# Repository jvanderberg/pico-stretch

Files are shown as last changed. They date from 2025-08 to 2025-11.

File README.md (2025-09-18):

# Pico Stretch

This is an RP2350B Dev board that breaks out all 48 GPIO pins.

It follows the original footprint of the RP2040 dev board, but adds 12 pins on each side.

Pinout:

```
1	GPIO0	        64	VBUS
2	GPIO1	        63	VSYS
3	GND	            62	GND
4	GPIO2	        61	3v3
5	GPIO3	        60	3v3_EN
6	GPIO4	        59	ADC_VREF
7	GPIO5	        58	GPIO28
8	GND	            57	GND
9	GPIO6	        56	GPIO27
10	GPIO7	        55	GPIO26
11	GPIO8	        54	RUN
12	GPIO9	        53	GPIO22
13	GND 	        52	GND
14	GPIO10	        51	GPIO21
15	GPIO11	        50	GPIO20
16	GPIO12	        49	GPIO19
17	GPIO13	        48	GPIO18
18	GND	            47	GND
19	GPIO14	        46	GPIO17
20	GPIO15	        45	GPIO16
21	GPIO23	        44	GPIO47/ADC7
22	GPIO24          43	GPIO46/ADC6
23	GPIO25	        42	GPIO45/ADC5
24	GPIO29	        41	GPIO44/ADC4
25	GPIO30	        40	GPIO43/ADC3
26	GPIO31	        39	GPIO42/ADC2
27	GPIO32	        38	GPIO41/ADC1
28	GPIO33	        37	GPIO40/ADC0
29	GPIO34	        36	GPIO39
30	GPIO35	        35	GPIO38
31  GND             34  GND
32  GPIO36          33  GPIO37
```

## Production files for JLCPCB

The production files for JLCPCB are in the 'production' directory.

pico-stretch.zip is the zipped Gerber files.

bom.csv and positions.csv are the Bill of materials and placements files respectively.

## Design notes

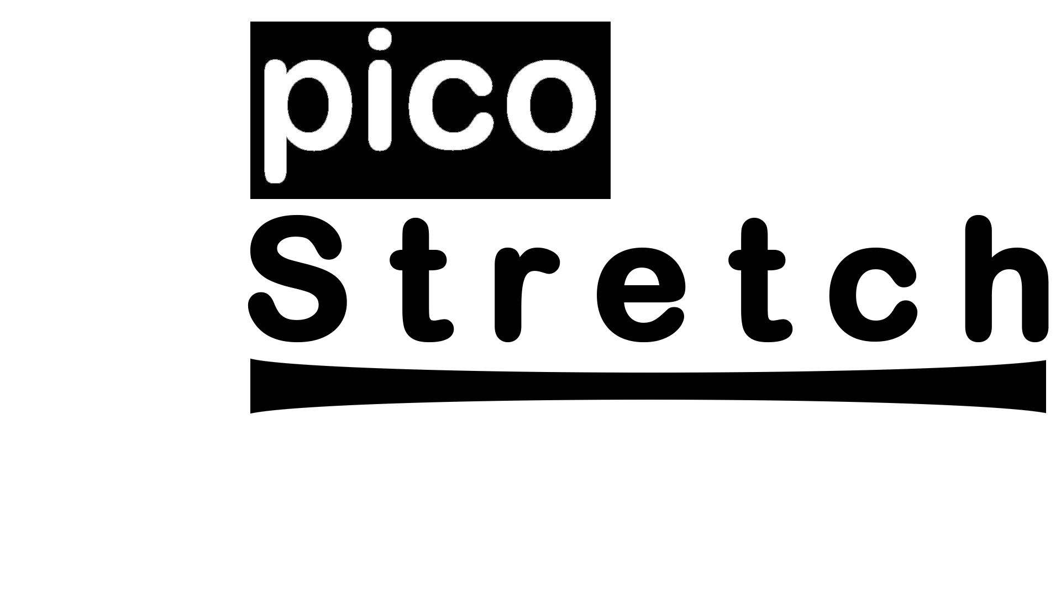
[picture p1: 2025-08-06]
picostretch.png

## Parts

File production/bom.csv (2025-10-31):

Designator | Footprint | Quantity | Value | LCSC Part #
BOOT1, RESET1 | KEY-SMD_4P-L4.2-W3.2-P2.20-LS5.1-TL | 2 | K2-1808SN-A4SW-01 | C92589
C1, C13, C16, C2, C21, C22, C23, C36, C7, C8 | C_0402 | 10 | 100nF | C1525
C10, C12 | C_0603 | 2 | 4.7uF | C19666
C11, C19 | C_0402 | 2 | 4.7uF | C23733
C15, C38, C39, C9 | C_0603 | 4 | 100nF | C14663
C17, C18 | C_0402 | 2 | 15pF | C1548
C24 | C_0603 | 1 | 4.7nF | C53987
C3, C4, C5, C6 | C_0402 | 4 | 100nF
C37, C40 | C_0603 | 2 | 10uF | C19702
D1 | POWERDI-123_L2.8-W1.8-LS3.7-RD | 1 | ~ | C110493
D2, D3 | D0402-BI | 2 | RCLAMP0521P.TCT-MS | C3029033
J2 | PinHeader_1x03_P2.54mm_Vertical | 1 | Conn_01x03_Pin
J4 | Castellated_Pad_64 | 1 | Conn_01x64_Castellated_Pads
L1 | IND-SMD_L2.0-W1.6_AOTA-B201610S3R3-101-T | 1 | ~ | C42411119
PWR_LED1 | D_0603 | 1 | Red | C2286
R1, R4 | R_0402 | 2 | 5.1kΩ | C25905
R10, R14, R16, R9 | R_0402 | 4 | 10kΩ | C25744
R11 | R_0402 | 1 | 100kΩ | C25741
R12 | R_0402 | 1 | 2kΩ | C4109
R15 | R_0402 | 1 | 470Ω | C25117
R2, R3, R6 | R_0402 | 3 | 33Ω | C25105
R28 | R_0603 | 1 | 1kΩ | C21190
R5 | R_0402 | 1 | 1kΩ | C11702
R7 | R_0603 | 1 | 1Ω | C22936
R8 | R_0603 | 1 | 200Ω | C8218
TP1, TP2 | TestPoint_Pad_1.0x1.0mm | 2 | TestPoint
U1 | QFN-80_L10.0-W10.0-P0.40-TL-EP3.4 | 1 | ~ | C42415655
U3 | SOT-23-5_L3.0-W1.7-P0.95-LS2.8-BR | 1 | ~ | C427602
U4 | SOIC-8_L5.3-W5.3-P1.27-LS8.0-BL | 1 | Winbond W25Q128JVSIQ | C97521
U5 | rpi_rmc20452t | 1 | RPI Radio Module 2
U6 | SOIC-8_3.9x4.9mm_P1.27mm | 1 | ESP-PSRAM32
USB1 | USB-C-SMD_TYPE-C-6PIN-2MD-073 | 1 | ~ | C2765186
X1 | CRYSTAL-SMD_4P-L3.2-W2.5-BL | 1 | ~ | C20625731

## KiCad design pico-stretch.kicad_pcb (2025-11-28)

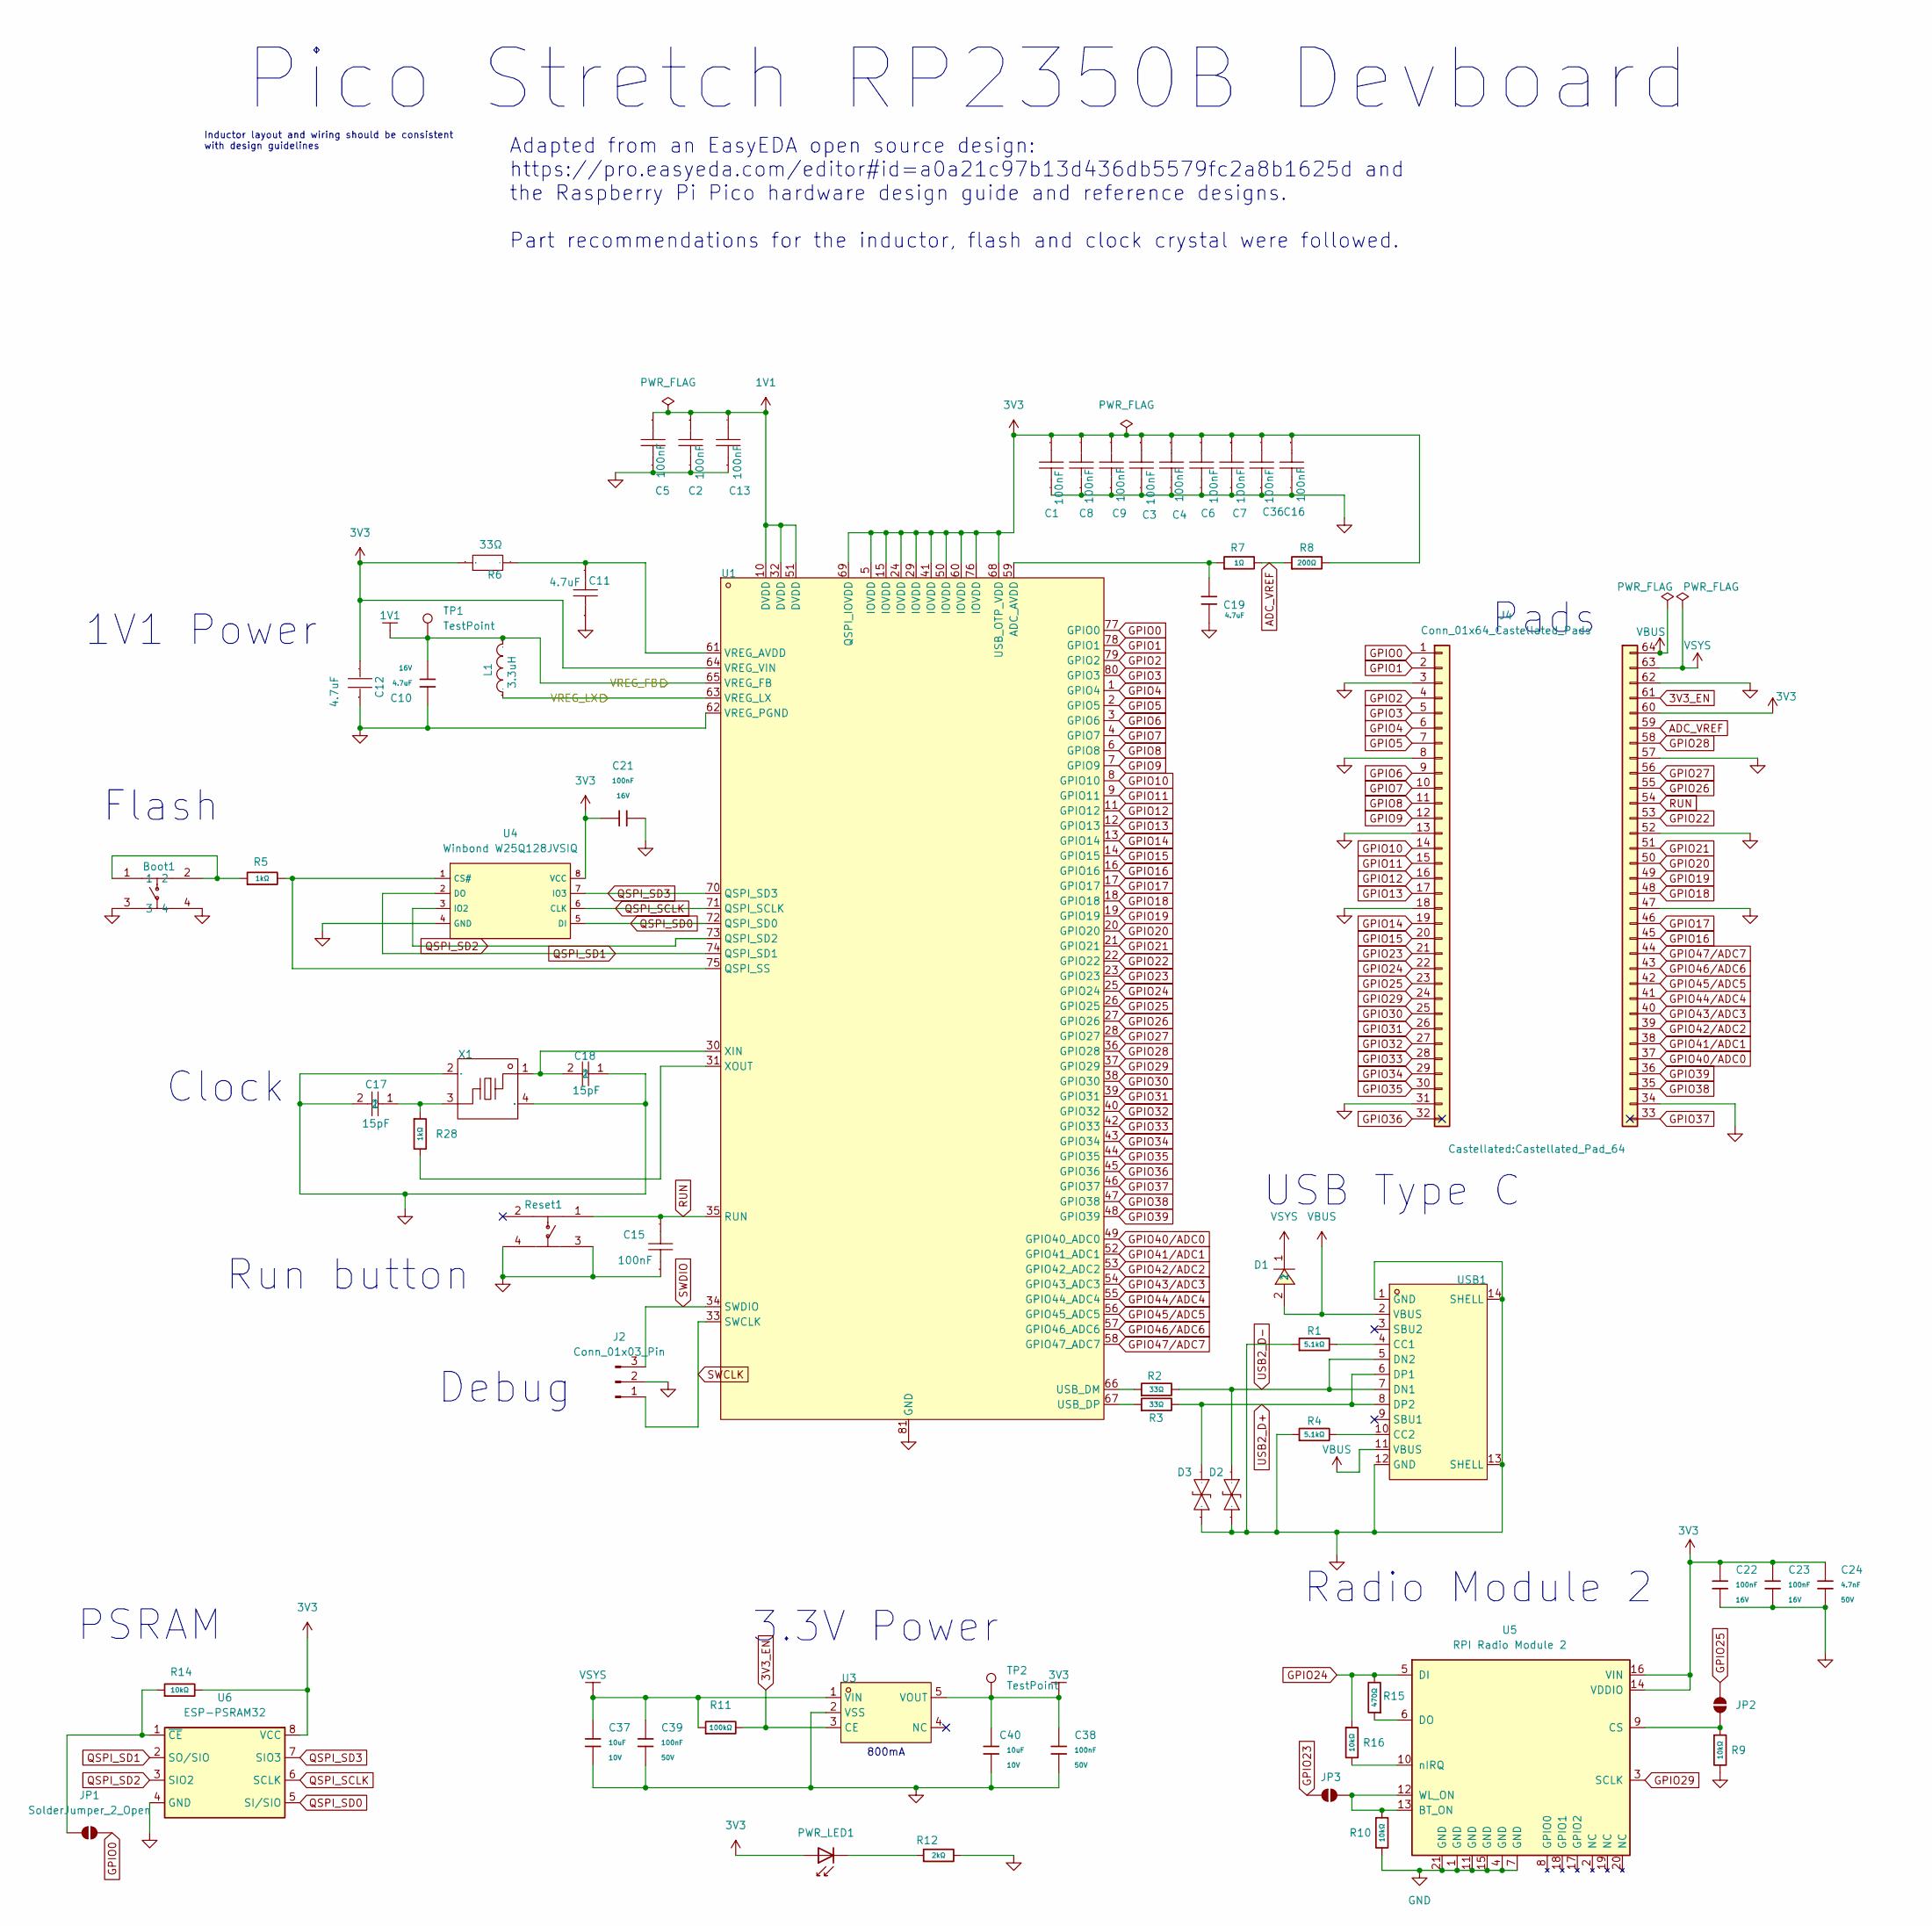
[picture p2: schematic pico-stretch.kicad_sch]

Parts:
Boot1: K2-1808SN-A4SW-01; KEY-SMD_4P-L4.2-W3.2-P2.20-LS5.1-TL; Manufacturer Part K2-1808SN-A4SW-01; LCSC Part Name 4.2mm*3.25mm
C1, C2, C3, C4, C5, C6, C7, C8, C13, C16, C36: 100nF; C0402; Manufacturer Part CL05B104KO5NNNC; LCSC Part Name 100nF ±10% 16V
C9, C15: 100nF; C0402; Voltage Rating 50V; Manufacturer Part CC0603KRX7R9BB104; LCSC Part Name 100nF ±10% 50V
C10: 4.7uF; C_0603; Voltage Rated 16V; Tolerance ±10%; Part CL10A475KO8NNNC; LCSC C19666
C11: 4.7uF; Manufacturer Part CL05A475MP5NRNC; LCSC Part Name 4.7uF ±20% 10V
C12: 4.7uF; Manufacturer Part CL10A475KO8NNNC; LCSC Part Name 4.7uF ±10% 16V
C17, C18: 15pF; C0402; Manufacturer Part 0402CG150J500NT; LCSC Part Name 15pF ±5% 50V
C19: 4.7uF; C_0402; Voltage Rated 10V; Tolerance ±20%; Part CL05A475MP5NRNC; LCSC C23733
C21, C22, C23: 100nF; C_0402; Voltage Rated 16V; Tolerance ±10%; Part CL05B104KO5NNNC; LCSC C1525
C24: 4.7nF; C_0603; Voltage Rated 50V; Tolerance ±10%; Part 0603B472K500NT; LCSC C53987
C37, C40: 10uF; C_0603; Voltage Rated 10V; Tolerance ±10%; Part CL10A106KP8NNNC; LCSC C19702
C38, C39: 100nF; C_0603; Voltage Rated 50V; Tolerance ±10%; Part CC0603KRX7R9BB104; LCSC C14663
D1: POWERDI-123_L2.8-W1.8-LS3.7-RD; Manufacturer Part DFLS130L-7; LCSC Part Name 电压:30V 电流:1A
D2, D3: RCLAMP0521P.TCT-MS; D0402-BI; Manufacturer Part RCLAMP0521P.TCT-MS; LCSC Part Name 双向TVS 5V截止 4A峰值脉冲 丝印N
J2: Conn_01x03_Pin; PinHeader_1x03_P2.54mm_Vertical
J4: Conn_01x64_Castellated_Pads; Castellated_Pad_64
JP1, JP2, JP3: SolderJumper_2_Open; SolderJumper-2_P1.3mm_Open_Pad1.0x1.5mm
L1: IND-SMD_L2.0-W1.6_AOTA-B201610S3R3-101-T; Manufacturer Part AOTA-B201610S3R3-101-T; LCSC Part Name AOTA-B201610S3R3-101-T
PWR_LED1: Red; D_0603; Part KT-0603R; LCSC C2286
R1, R4: 5.1kΩ; R_0402; Overload Voltage (Max) 50V; Tolerance ±1%; Part 0402WGF5101TCE; LCSC C25905
R2, R3: 33Ω; R_0402; Overload Voltage (Max) 50V; Tolerance ±1%; Part 0402WGF330JTCE; LCSC C25105
R5: 1kΩ; R_0402; Overload Voltage (Max) 50V; Tolerance ±1%; Part 0402WGF1001TCE; LCSC C11702
R6: 33Ω; R0402; Manufacturer Part 0402WGF330JTCE; LCSC Part Name 33Ω ±1% 62.5mW 厚膜电阻
R7: 1Ω; R_0603; Overload Voltage (Max) 75V; Tolerance ±1%; Part 0603WAF100KT5E; LCSC C22936
R8: 200Ω; R_0603; Overload Voltage (Max) 75V; Tolerance ±1%; Part 0603WAF2000T5E; LCSC C8218
R9, R10, R14, R16: 10kΩ; R_0402; Overload Voltage (Max) 50V; Tolerance ±1%; Part 0402WGF1002TCE; LCSC C25744
R11: 100kΩ; R_0402; Overload Voltage (Max) 50V; Tolerance ±1%; Part 0402WGF1003TCE; LCSC C25741
R12: 2kΩ; R_0402; Overload Voltage (Max) 50V; Tolerance ±1%; Part 0402WGF2001TCE; LCSC C4109
R15: 470Ω; R_0402; Overload Voltage (Max) 50V; Tolerance ±1%; Part 0402WGF4700TCE; LCSC C25117
R28: 1kΩ; R_0603; Overload Voltage (Max) 75V; Tolerance ±1%; Part 0603WAF1001T5E; LCSC C21190
Reset1: K2-1808SN-A4SW-01; KEY-SMD_4P-L4.2-W3.2-P2.20-LS5.1-TL; Manufacturer Part K2-1808SN-A4SW-01; LCSC Part Name 4.2mm*3.25mm
TP1, TP2: TestPoint; TestPoint_Pad_1.0x1.0mm
U1: QFN-80_L10.0-W10.0-P0.40-TL-EP3.4; Manufacturer Part RP2350B; LCSC Part Name RP2350B
U3: SOT-23-5_L3.0-W1.7-P0.95-LS2.8-BR; Manufacturer Part ME6217C33M5G; LCSC Part Name ME6217C33M5G
U4: Winbond W25Q128JVSIQ; SOIC-8_L5.3-W5.3-P1.27-LS8.0-BL; Part W25Q128JVSIQ; LCSC C97521
U5: RPI Radio Module 2; rpi_rmc20452t
U6: ESP-PSRAM32; SOIC-8_3.9x4.9mm_P1.27mm
USB1: USB-C-SMD_TYPE-C-6PIN-2MD-073; Manufacturer Part TYPE-C 16PIN 2MD(073); LCSC Part Name Type-C 母 卧贴
X1: Manufacturer Part ABM8-272-T3; LCSC Part Name ABM8-272-T3

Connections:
1V1: C2.1, C5.1, C10.2, C13.2, L1.2, TP1.1, U1.10 (DVDD), U1.32 (DVDD), U1.51 (DVDD), U1.65 (VREG_FB)
3V3: C1.1, C3.1, C4.1, C6.1, C7.1, C8.2, C9.2, C12.2, C16.1, C21.1, C22.1, C23.1, C24.1, C36.2, C38.1, C40.1, J4.60, PWR_LED1.2, R6.1, R8.2, R14.2, TP2.1, U1.5 (IOVDD), U1.15 (IOVDD), U1.24 (IOVDD), U1.29 (IOVDD), U1.41 (IOVDD), U1.50 (IOVDD), U1.60 (IOVDD), U1.64 (VREG_VIN), U1.68 (USB_OTP_VDD), U1.69 (QSPI_IOVDD), U1.76 (IOVDD), U3.5 (VOUT), U4.8 (VCC), U5.14 (VDDIO), U5.16 (VIN), U6.8 (VCC)
3V3_EN: J4.61, R11.2, U3.3 (CE)
/VREG_LX: L1.1, U1.63 (VREG_LX)
ADC_VREF: J4.59, R7.2, R8.1
GND: Boot1.3, Boot1.4, C1.2, C2.2, C3.2, C4.2, C5.2, C6.2, C7.2, C8.1, C9.1, C10.1, C11.1, C12.1, C13.1, C15.1, C16.2, C17.2, C18.1, C19.2, C21.2, C22.2, C23.2, C24.2, C36.1, C37.2, C38.2, C39.2, C40.2, D2.1, D3.1, J2.2, J4.3, J4.8, J4.13, J4.18, J4.31, J4.34, J4.47, J4.52, J4.57, J4.62, R1.1, R4.1, R9.2, R10.2, R12.2, Reset1.3, Reset1.4, U1.62 (VREG_PGND), U1.81 (GND), U3.2 (VSS), U4.4 (GND), U5.1 (GND), U5.4 (GND), U5.7 (GND), U5.11 (GND), U5.15 (GND), U5.21 (GND), U6.4 (GND), USB1.1 (GND), USB1.12 (GND), USB1.13 (SHELL), USB1.14 (SHELL), X1.2 (GND), X1.4 (GND)
GPIO0: J4.1, JP1.2 (B), U1.77 (GPIO0)
GPIO1: J4.2, U1.78 (GPIO1)
GPIO2: J4.4, U1.79 (GPIO2)
GPIO3: J4.5, U1.80 (GPIO3)
GPIO4: J4.6, U1.1 (GPIO4)
GPIO5: J4.7, U1.2 (GPIO5)
GPIO6: J4.9, U1.3 (GPIO6)
GPIO7: J4.10, U1.4 (GPIO7)
GPIO8: J4.11, U1.6 (GPIO8)
GPIO9: J4.12, U1.7 (GPIO9)
GPIO10: J4.14, U1.8 (GPIO10)
GPIO11: J4.15, U1.9 (GPIO11)
GPIO12: J4.16, U1.11 (GPIO12)
GPIO13: J4.17, U1.12 (GPIO13)
GPIO14: J4.19, U1.13 (GPIO14)
GPIO15: J4.20, U1.14 (GPIO15)
GPIO16: J4.45, U1.16 (GPIO16)
GPIO17: J4.46, U1.17 (GPIO17)
GPIO18: J4.48, U1.18 (GPIO18)
GPIO19: J4.49, U1.19 (GPIO19)
GPIO20: J4.50, U1.20 (GPIO20)
GPIO21: J4.51 (Pin_61), U1.21 (GPIO21)
GPIO22: J4.53, U1.22 (GPIO22)
GPIO23: J4.21, JP3.1 (A), U1.23 (GPIO23)
GPIO24: J4.22, R15.2, R16.1, U1.25 (GPIO24), U5.5 (DI)
GPIO25: J4.23, JP2.2 (B), U1.26 (GPIO25)
GPIO26: J4.55, U1.27 (GPIO26)
GPIO27: J4.56, U1.28 (GPIO27)
GPIO28: J4.58, U1.36 (GPIO28)
GPIO29: J4.24, U1.37 (GPIO29), U5.3 (SCLK)
GPIO30: J4.25, U1.38 (GPIO30)
GPIO31: J4.26, U1.39 (GPIO31)
GPIO32: J4.27, U1.40 (GPIO32)
GPIO33: J4.28, U1.42 (GPIO33)
GPIO34: J4.29, U1.43 (GPIO34)
GPIO35: J4.30, U1.44 (GPIO35)
GPIO36: J4.32, U1.45 (GPIO36)
GPIO37: J4.33, U1.46 (GPIO37)
GPIO38: J4.35, U1.47 (GPIO38)
GPIO39: J4.36, U1.48 (GPIO39)
GPIO40/ADC0: J4.37, U1.49 (GPIO40_ADC0)
GPIO41/ADC1: J4.38, U1.52 (GPIO41_ADC1)
GPIO42/ADC2: J4.39, U1.53 (GPIO42_ADC2)
GPIO43/ADC3: J4.40, U1.54 (GPIO43_ADC3)
GPIO44/ADC4: J4.41, U1.55 (GPIO44_ADC4)
GPIO45/ADC5: J4.42, U1.56 (GPIO45_ADC5)
GPIO46/ADC6: J4.43, U1.57 (GPIO46_ADC6)
GPIO47/ADC7: J4.44, U1.58 (GPIO47_ADC7)
unnamed: Boot1.1, Boot1.2, R5.1
unnamed: C17.1, R28.1, X1.3
unnamed: JP1.1 (A), R14.1, U6.1 (~CE)
unnamed: JP2.1 (A), R9.1, U5.9 (CS)
unnamed: JP3.2 (B), R10.1, U5.12 (WL_ON), U5.13 (BT_ON)
unnamed: PWR_LED1.1, R12.1
unnamed: C19.1, R7.1, U1.59 (ADC_AVDD)
unnamed: R5.2, U1.75 (QSPI_SS), U4.1 (CS#)
unnamed: R2.1, U1.66 (USB_DM)
unnamed: R3.1, U1.67 (USB_DP)
unnamed: C11.2, R6.2, U1.61 (VREG_AVDD)
unnamed: C18.2, U1.30 (XIN), X1.1
unnamed: R28.2, U1.31 (XOUT)
unnamed: R15.1, U5.6 (DO)
unnamed: R16.2, U5.10 (nIRQ)
unnamed: R1.2, USB1.4 (CC1)
unnamed: R4.2, USB1.10 (CC2)
QSPI_SCLK: U1.71 (QSPI_SCLK), U4.6 (CLK), U6.6 (SCLK)
QSPI_SD0: U1.72 (QSPI_SD0), U4.5 (DI), U6.5 (SI/SIO)
QSPI_SD1: U1.74 (QSPI_SD1), U4.2 (DO), U6.2 (SO/SIO)
QSPI_SD2: U1.73 (QSPI_SD2), U4.3 (IO2), U6.3 (SIO2)
QSPI_SD3: U1.70 (QSPI_SD3), U4.7 (IO3), U6.7 (SIO3)
RUN: C15.2, J4.54, Reset1.1, U1.35 (RUN)
SWCLK: J2.1, U1.33 (SWCLK)
SWDIO: J2.3, U1.34 (SWDIO)
USB2_D+: D3.2, R3.2, USB1.6 (DP1), USB1.8 (DP2)
USB2_D-: D2.2, R2.2, USB1.5 (DN2), USB1.7 (DN1)
VBUS: D1.2, J4.64, USB1.2 (VBUS), USB1.11 (VBUS)
VSYS: C37.1, C39.1, D1.1, J4.63, R11.1, U3.1 (VIN)

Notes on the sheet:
Clock
PSRAM
USB Type C
Flash
3.3V Power
Radio Module 2
Debug
Run button
Pico Stretch RP2350B Devboard
Inductor layout and wiring should be consistent with design guidelines
1V1 Power
Pads
Adapted from an EasyEDA open source design: https://pro.easyeda.com/editor#id=a0a21c97b13d436db5579fc2a8b1625d and the Raspberry Pi Pico hardware design guide and reference designs. Part recommendations for the inductor, flash and clock crystal were followed.
800mA

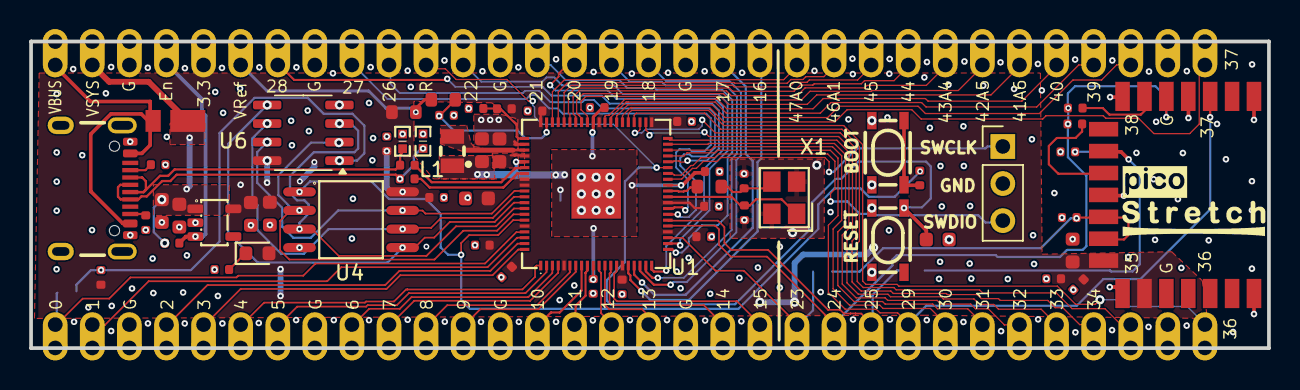
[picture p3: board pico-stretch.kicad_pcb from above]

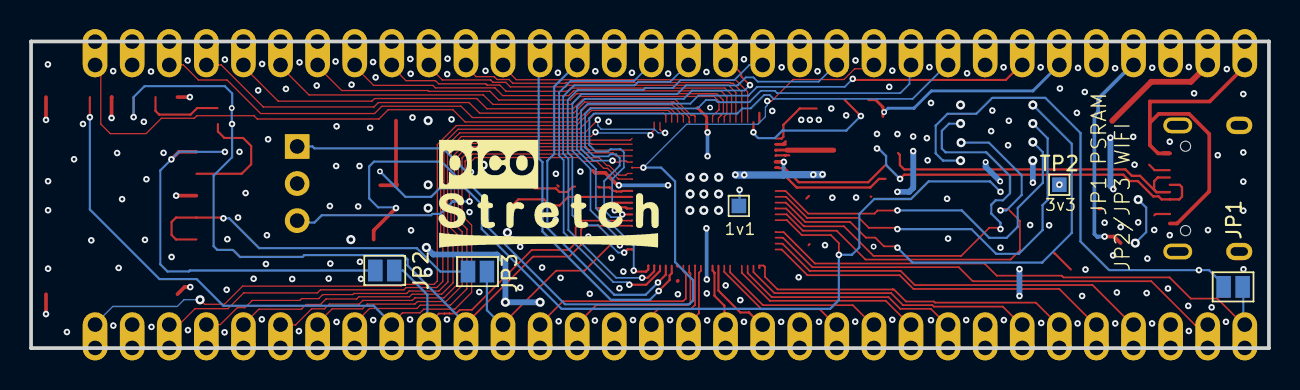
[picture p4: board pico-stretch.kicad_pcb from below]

Board: 4 copper layers, 84.8 x 21.0 mm, 64 parts (5 on the bottom side), 83 nets.

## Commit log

2025-06-16 Push first version
    [RP2350 Dev Board.kicad_pcb, RP2350 Dev Board.kicad_sch, bom.csv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]
2025-06-16 Small changes
    [RP2350 Dev Board.kicad_pcb]
2025-06-17 Re-did schematic
    [RP2350 Dev Board.kicad_pcb, RP2350 Dev Board.kicad_sch]
2025-06-18 Updated footprints, more basic parts
    [RP2350 Dev Board.kicad_pcb, RP2350 Dev Board.kicad_sch, bom.csv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]
2025-07-07 Added wifi and PSRAM
    [RP2350 Dev Board.kicad_pcb, RP2350 Dev Board.kicad_sch]
2025-07-10 Super version
    [RP2350 Dev Board.kicad_pcb, RP2350 Dev Board.kicad_sch]
2025-08-06 final cleanup
    [RP2350 Dev Board.kicad_pcb, RP2350 Dev Board.kicad_sch]
2025-08-06 Cleanup of connectors
    [RP2350 Dev Board.kicad_pcb]
2025-09-17 Before RM2 reset
    [RP2350 Dev Board.kicad_pcb, RP2350 Dev Board.kicad_sch]
2025-09-18 Renames and doc updates
    [pico-stretch.kicad_pcb, pico-stretch.kicad_sch]
2025-09-18 Fixes, 3v3 front pour, change to signal/gnd/gnd/signal stackup
    [pico-stretch.kicad_pcb]
2025-09-19 Updated production bom, positions, gerbers
    [bom.csv, designators.csv, positions.csv]
2025-09-19 Minor text update
    [pico-stretch.kicad_sch]
2025-09-19 Fixes after review
    [bom.csv, designators.csv, pico-stretch.kicad_pcb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]
2025-09-20 Fixed vias
    [pico-stretch.kicad_pcb]
2025-10-31 Major re-work for castellated pads and PSRAM on top
    [bom.csv, designators.csv, pico-stretch.kicad_pcb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]
2025-10-31 Going to prod
    [pico-stretch.kicad_pcb, positions.csv]
2025-11-28 Updated labels and production files
    [pico-stretch.kicad_pcb]
